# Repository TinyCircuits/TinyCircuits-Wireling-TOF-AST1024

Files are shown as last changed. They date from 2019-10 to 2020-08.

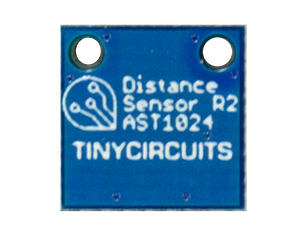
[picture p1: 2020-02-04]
images/AST1024-Learn-Photo-02.png

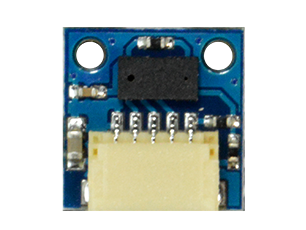
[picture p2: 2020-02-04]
images/AST1024-Learn-Photo-01.png

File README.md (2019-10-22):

# TinyCircuits Wireling TOF
# AST1024 Rev2

The design files are located under design_files/ for the TinyCircuits AST1024 Rev 2 PCB. This is a Wireling board which features the ST VL53L0X IR Time-of-Flight sensor capable of measuring absolute range up to 2m and is most responsive to reflective materials.

Format is in Cadsoft Eagle format - Eagle version 6.2 was used for the original design.

For more infomation on this, check out the product page at TinyCircuits.com

# License:

Design by TinyCircuits.
All design files are released under the Creative Commons Attribution Share-Alike 3.0 License, see the following link for details: http://creativecommons.org/licenses/by-sa/3.0

All text above must be included in any redistribution or derived design

This project uses designs and concepts developed as part of the Arduino project and the LilyPad project.  The TinyCircuits design files themselves (schematics, PCB and libraries) are not directly derived from these works' design files and have been created new, however the concepts and basic architecture behind the TinyDuino and TinyLily products are derived and we thank the hard work of the organizations below for their contributions to open-source hardware:
  
Original Arduino Uno Design by Team Arduino

LilyPad Arduino Design by Leah Buechley and Sparkfun Electronics

Please support the open-source hardware community

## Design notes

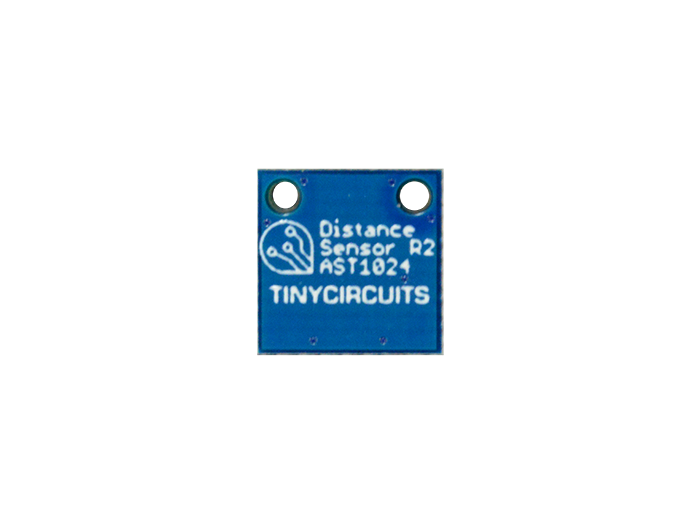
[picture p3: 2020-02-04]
images/AST1024-Product-Photo-02.png

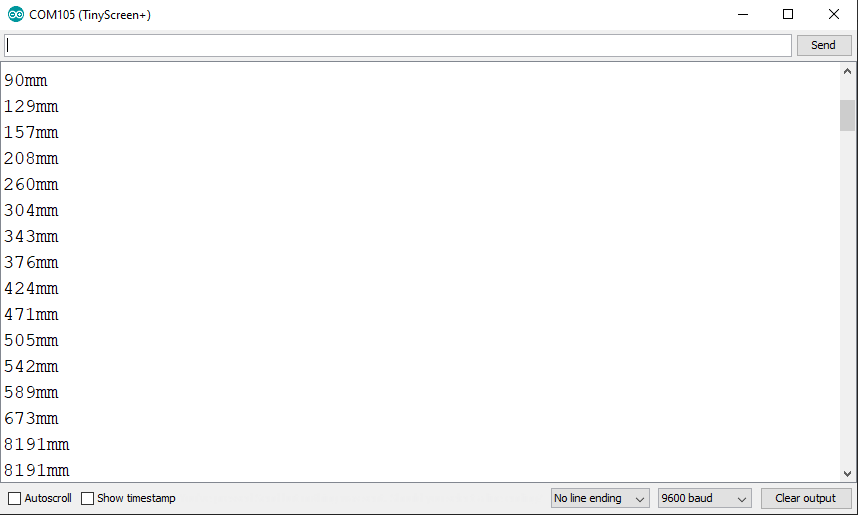
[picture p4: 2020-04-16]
images/AST1024-Learn-Photo-03.png

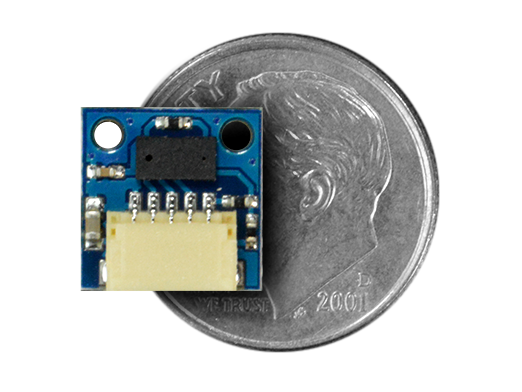
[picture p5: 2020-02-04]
images/AST1024-Product-Photo-03.png

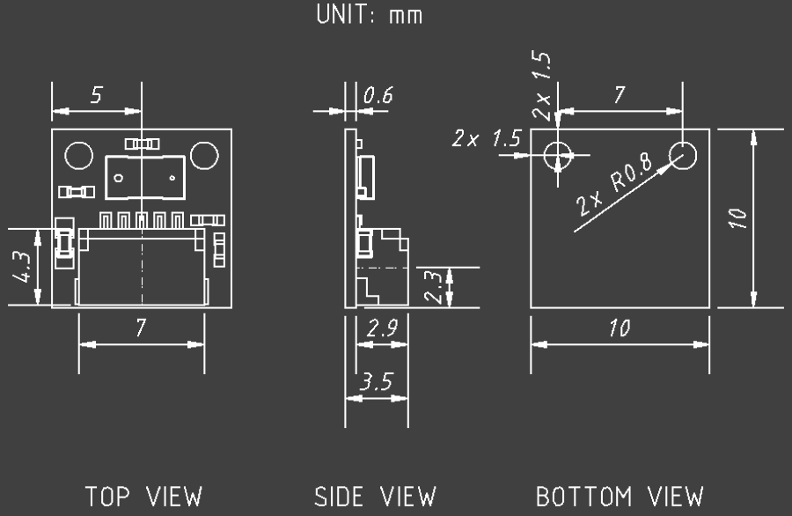
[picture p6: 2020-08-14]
cad/Wireling_TOF_AST1024_REV2-DETAILED_DRAWING_COMPACT-PNG.png

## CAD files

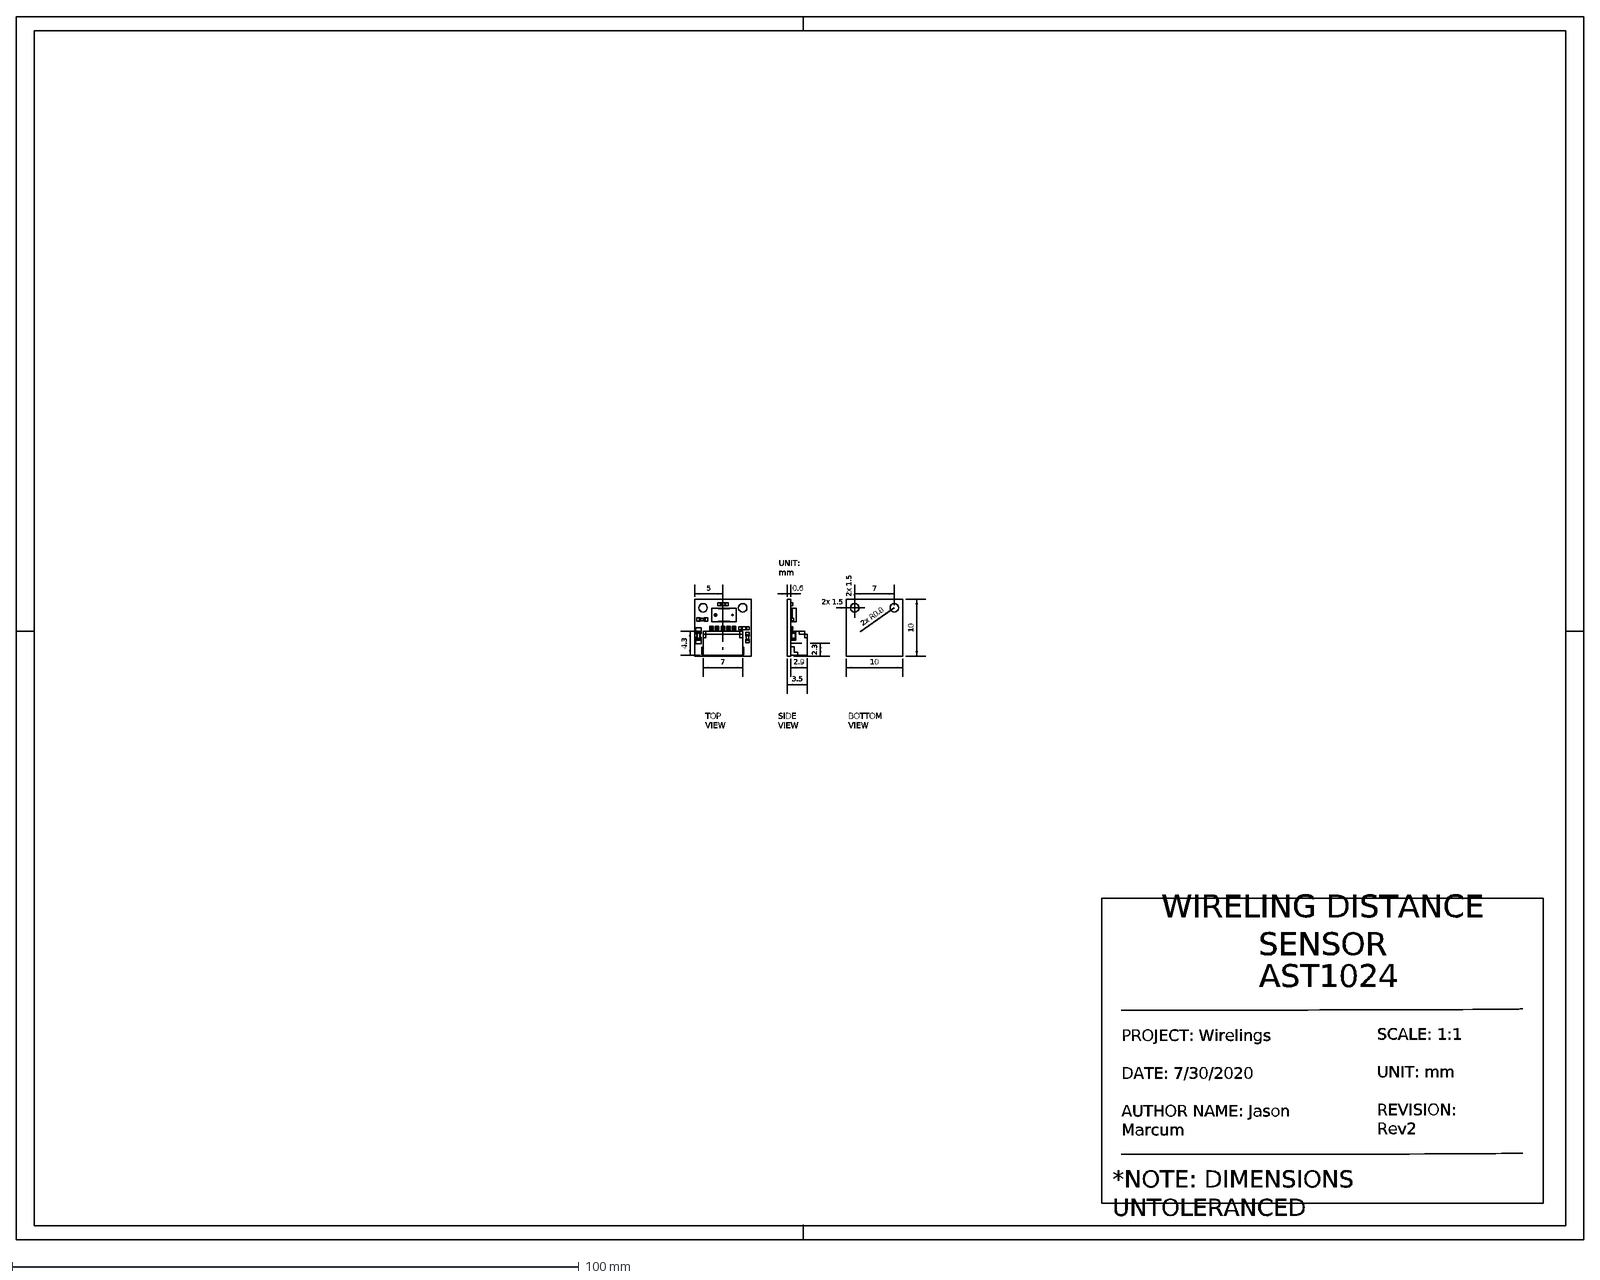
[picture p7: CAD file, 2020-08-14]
cad/Wireling_TOF_AST1024_REV2-DETAILED_DRAWING-DXF.dxf
*NOTE: DIMENSIONS UNTOLERANCED
UNIT: mm
7
4.3
5
2.9
3.5
2.3
0.6
2x 1.5
2x R0.8
10
TOP VIEW
BOTTOM VIEW
SIDE VIEW
WIRELING DISTANCE SENSOR
AST1024
SCALE: 1:1 UNIT: mm REVISION: Rev2
PROJECT: Wirelings DATE: 7/30/2020 AUTHOR NAME: Jason Marcum

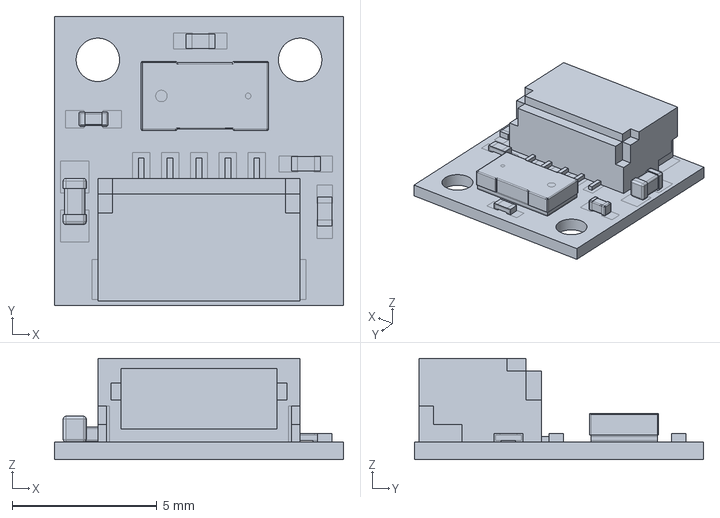
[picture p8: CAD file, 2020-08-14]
cad/Wireling_TOF_AST1024_REV2-IGES.iges
10.0 x 10.0 x 3.50 mm

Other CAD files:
cad/Wireling_TOF_AST1024_REV2-STL.stl
cad/Wireling_TOF_AST1024_REV2-STEP.step

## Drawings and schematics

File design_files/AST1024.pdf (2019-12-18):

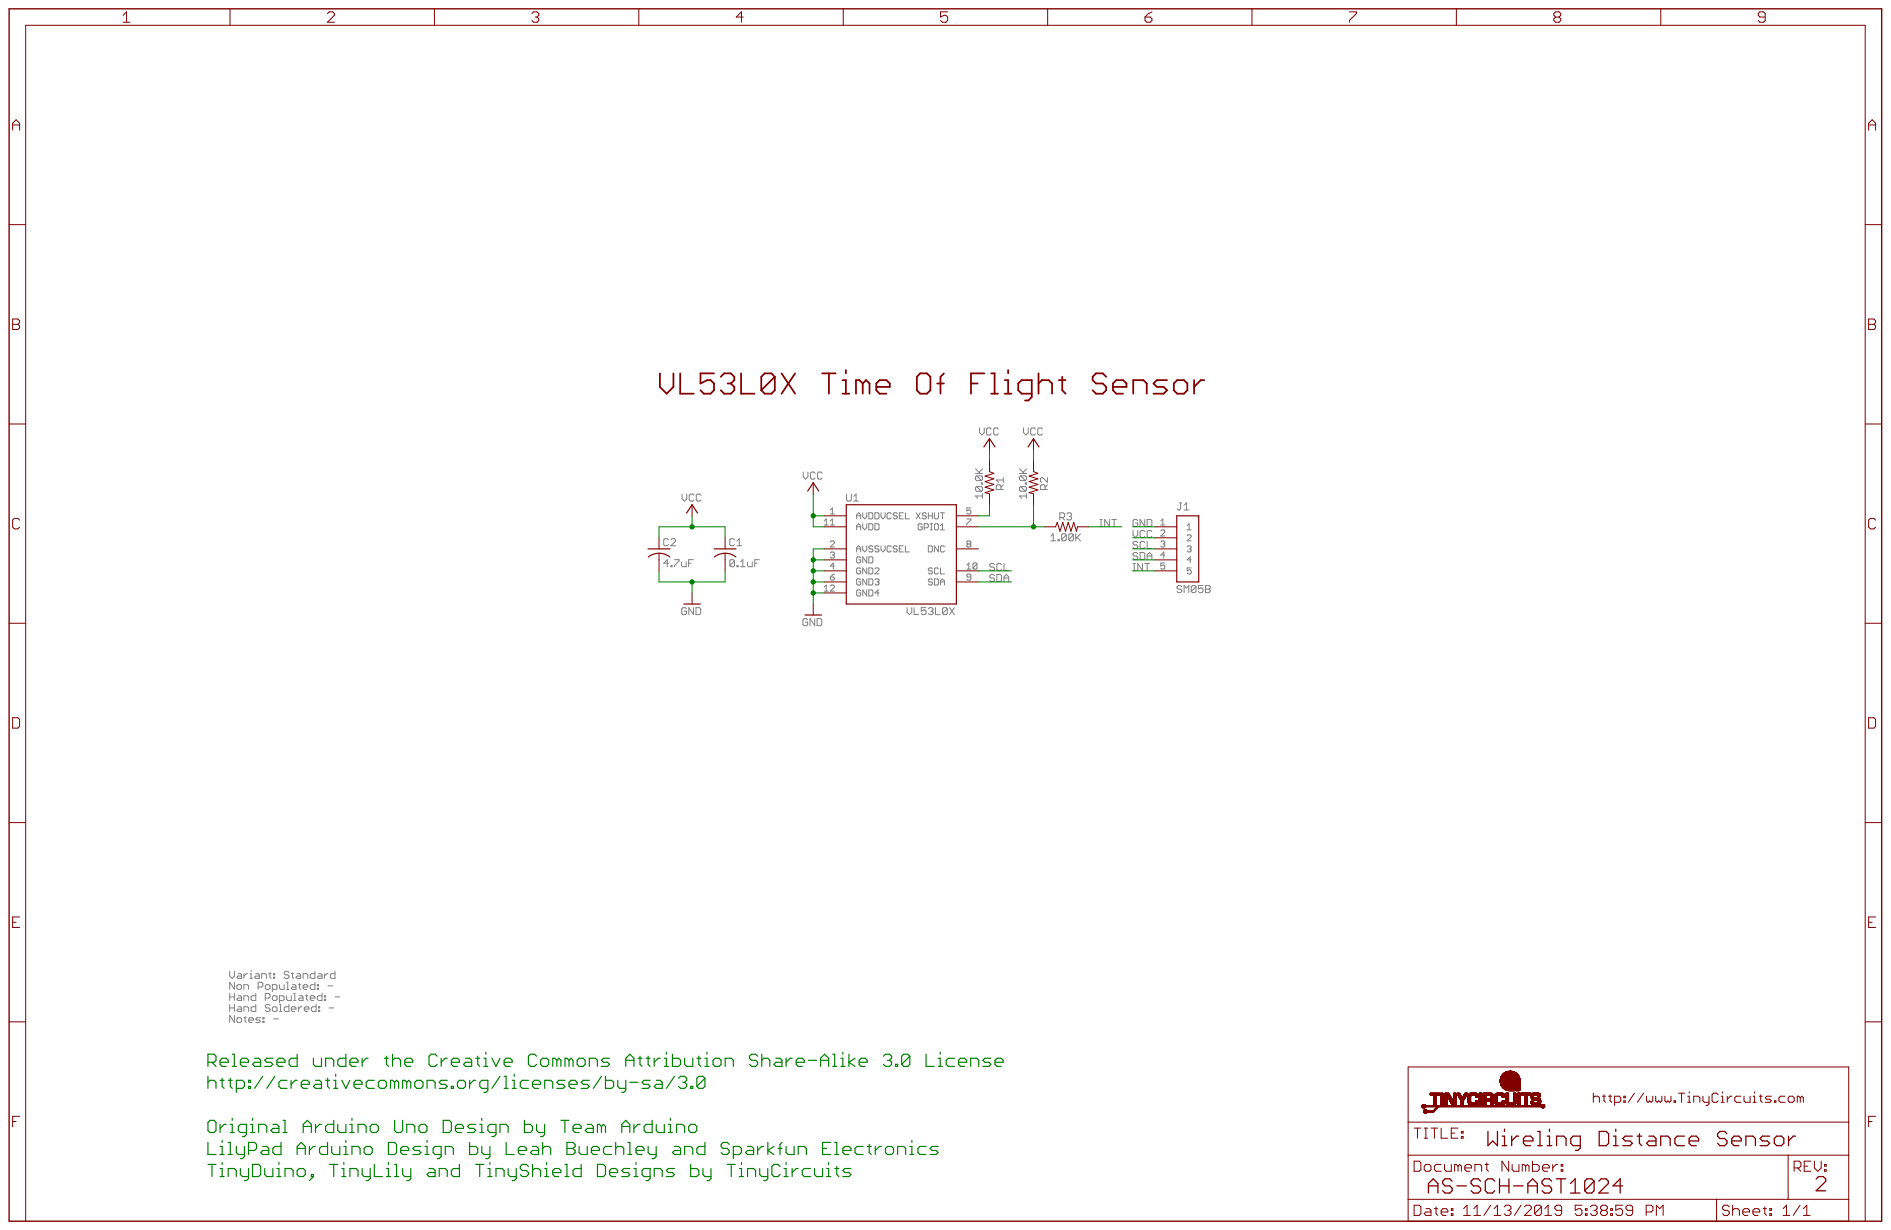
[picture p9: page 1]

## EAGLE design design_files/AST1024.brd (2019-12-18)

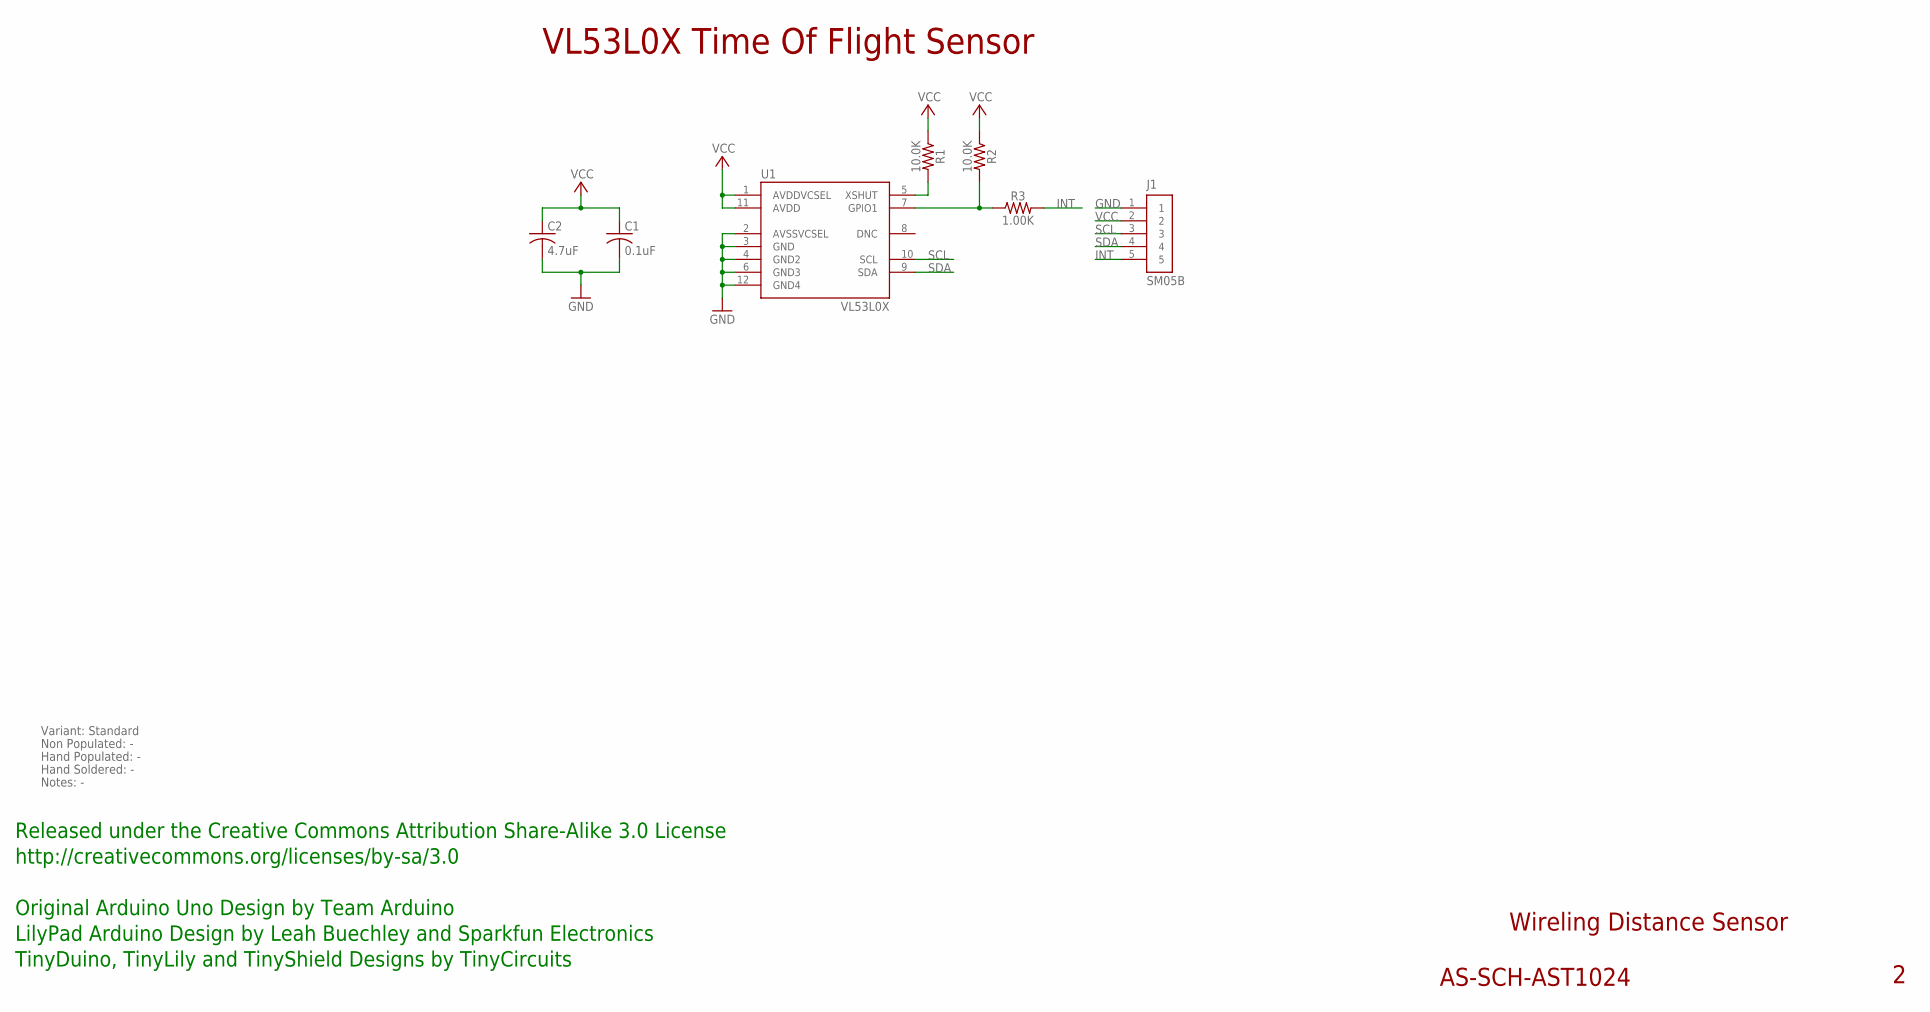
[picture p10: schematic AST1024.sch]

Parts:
C1: 0.1uF; C0402
C2: 4.7uF; C0603; PARTNO AS-ITM-00088
J1: SM05B; JST_SH_5X1_EDGE
R1: 10.0K; 0402
R2: 10.0K; 0402; PARTNO AS-ITM-00032
R3: 1.00K; 0402; PARTNO AS-ITM-00003
U1: VL53L0X

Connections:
GND: C1.2, C2.2, J1.1, U1.2 (AVSSVCSEL), U1.3 (GND), U1.4 (GND2), U1.6 (GND3), U1.12 (GND4)
GPIO1: R2.2, R3.1, U1.7 (GPIO1)
INT: J1.5, R3.2
unnamed: R1.2, U1.5 (XSHUT)
SCL: J1.3, U1.10 (SCL)
SDA: J1.4, U1.9 (SDA)
VCC: C1.1, C2.1, J1.2, R1.1, R2.1, U1.1 (AVDDVCSEL), U1.11 (AVDD)

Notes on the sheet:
Wireling Distance Sensor
AS-SCH-AST1024
VL53L0X Time Of Flight Sensor
Released under the Creative Commons Attribution Share-Alike 3.0 License
http://creativecommons.org/licenses/by-sa/3.0
Original Arduino Uno Design by Team Arduino
TinyDuino, TinyLily and TinyShield Designs by TinyCircuits
LilyPad Arduino Design by Leah Buechley and Sparkfun Electronics
Variant: Standard
Non Populated: -
Hand Populated: -
Hand Soldered: -
Notes: -

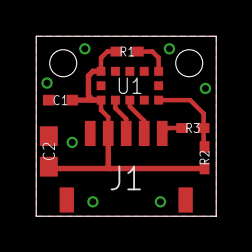
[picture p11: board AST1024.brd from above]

Board: 2 copper layers, 10.0 x 10.0 mm, 8 parts (0 on the bottom side), 7 nets.

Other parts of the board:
U$1: DOCFIELD-TINYCIRCUITS-PCB

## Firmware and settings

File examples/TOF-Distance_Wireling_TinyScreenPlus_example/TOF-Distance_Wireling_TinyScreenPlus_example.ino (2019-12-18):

/*************************************************************************
 * Time of Flight Distance Sensor Wireling 
 * This example shows how to use continuous mode to take, and print
 * range measurements with the VL53L0X Wireling. It is based on
 * vl53l0x_ContinuousRanging_Example.c from the VL53L0X API.
 *
 * The range readings are in units of mm.
 * 
 * Hardware by: TinyCircuits
 * Modified by: Laveréna Wienclaw for TinyCircuits 
 * Last Modified: 12/18/19
 *************************************************************************/

#include <Wire.h>       // For I2C communication
#include "VL53L0X.h"    // For interfacing with the Time-of-Flight Distance sensor
#include <TinyScreen.h> // For interfacing with the TinyScreen+
#include <Wireling.h>   // For interfacing with Wirelings

// TinyScreen+ variables
TinyScreen display = TinyScreen(TinyScreenPlus);
const int background = TS_8b_Black;

VL53L0X distanceSensor; // Name of sensor 
const int tofPort = 0;  // Port # of sensor (Found on Wireling Adapter Board)

const int averageCount = 1;
int average[averageCount];
int averagePos = 0;

#if defined(ARDUINO_ARCH_AVR)
#define SerialMonitorInterface Serial
#elif defined(ARDUINO_ARCH_SAMD)
#define SerialMonitorInterface SerialUSB
#endif

void setup() {
  delay(200);              // Sensor Startup time
  SerialMonitorInterface.begin(115200); // Set Baud Rate
  Wire.begin();            // Begin I2C communication

  // Enable power & select port
  Wireling.begin(); 
  // Select the port of the distance sensor (this number corresponds 
  // with port #'s on the Wireling adapter board)
  Wireling.selectPort(tofPort);

  // TinyScreen appearance variables are set
  display.begin();
  display.setFlip(true);
  display.setBrightness(15); 
  display.setFont(thinPixel7_10ptFontInfo);
  display.fontColor(TS_8b_White, background);

  // Initialize the distance sensor and set a timeout
  distanceSensor.init();
  distanceSensor.setTimeout(500);

  // Start continuous back-to-back mode (take readings as
  // fast as possible).  To use continuous timed mode
  // instead, provide a desired inter-measurement period in
  // ms (e.g. sensor.startContinuous(100))
  distanceSensor.setMeasurementTimingBudget(200000);
  distanceSensor.startContinuous();
}

void loop() {
  // Calculate the average position of the distance sensor
  unsigned long averageRead = 0;
  average[averagePos] = distanceSensor.readRangeContinuousMillimeters();
  averagePos++;
  if (averagePos >= averageCount)averagePos = 0;
  for (int i = 0; i < averageCount; i++) {
    averageRead += (unsigned long)average[i];
  }
  averageRead /= (unsigned long)averageCount;

  // Print the average position to the TinyScreen and the Serial Monitor
  printToScreen(averageRead);
  SerialMonitorInterface.print(averageRead);
  SerialMonitorInterface.println("mm");
  
}

// Print averageRead to the TinyScreen
void printToScreen(unsigned long averageRead){
  // This will make the screen look a little unsteady but is needed in order
  // to clear old values 
  display.clearScreen();
  
  display.setCursor(0, 0); 
  display.print("TOF Sensor Test"); 
  
  display.setCursor(0, 12);
  display.print(averageRead);

  if (distanceSensor.timeoutOccurred()) {
    display.print("-");
  }
}

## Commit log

2019-12-17 updated documentation
    [AST1024.brd, AST1024.sch]
2020-08-14 Add CAD data
    [Wireling_TOF_AST1024_REV2-DETAILED_DRAWING-DXF.dxf, Wireling_TOF_AST1024_REV2-IGES.iges, Wireling_TOF_AST1024_REV2-STEP.step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]
